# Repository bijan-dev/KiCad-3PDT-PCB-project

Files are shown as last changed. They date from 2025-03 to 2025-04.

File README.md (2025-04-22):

# KiCad-3PDT-PCB-project
A 3PDT PCB for guitar pedals

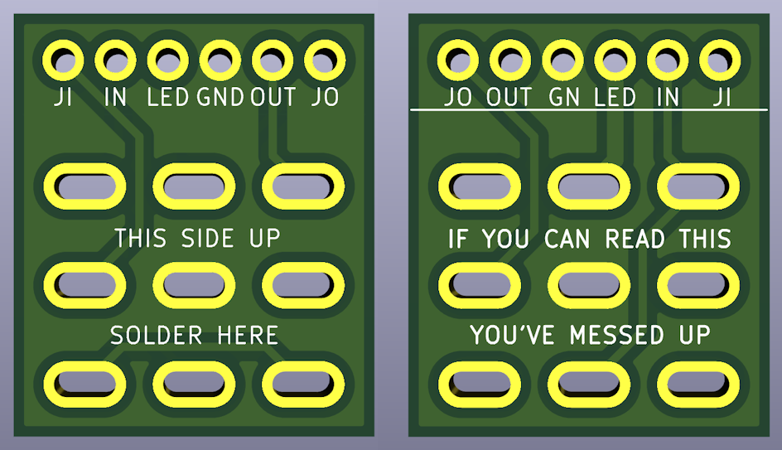
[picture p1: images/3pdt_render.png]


Hello, this is a KiCad project for a 3PDT PCB board.
This will allow a guitar pedal with a 3PDT [like this](https://stompboxparts.com/footswitches/3pdt-footswitch-solder-lug-vimex/) to be wired in true bypass.

* JI = Input Jack
* IN = PCB Input
* LED = LED connection (assumes an offboard current limiting resistor eg. 4.7k Ohm. Please add one if your effect PCB doesn't have one)
* GND = Ground connection
* OUT = PCB Output
* JO = Output Jack

The wire pads have a pitch of 2.54mm (0.1") to match that of common ribbon cables.

Board width is 17.5mm, height is 20.5mm.

Huge thank you to [Mad Bean](https://www.madbeanpedals.com/) for the pad and 3PDT footprints, their footprint library is the GOAT.

---

**This board is now verified!** I ordered some copies from OshPark, and used one in a new build. It works! It's suprisingly tiny!

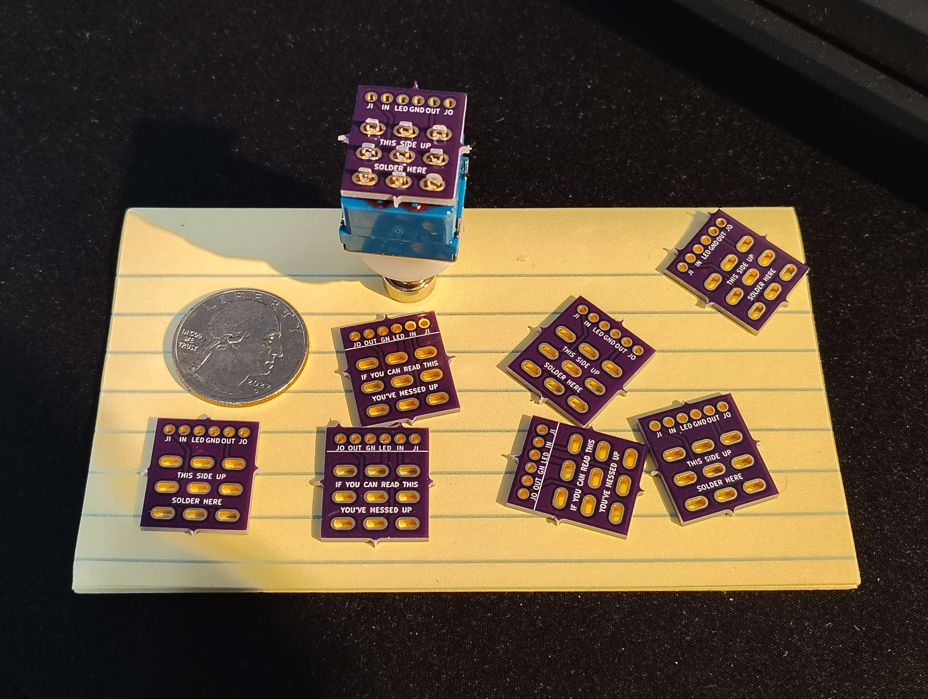
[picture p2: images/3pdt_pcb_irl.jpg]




---

# If you would like to order one

The gerber files are included in the repo.

Click into the `3pdt_pcb_fab_files.zip` file in this repo, then download that zip file.

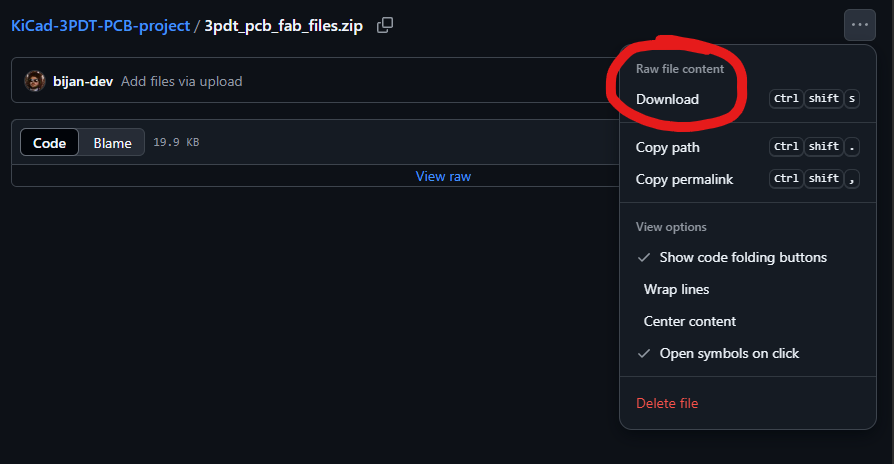
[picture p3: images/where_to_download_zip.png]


Then you can use a board fabricator like JLCPCB and upload that zip onto their site.

If you need the gerber files compressed in a different format than .zip, I've included them in the folder `3pdt_pcb_fab_files`.

Here's where to put the file on JLCPCBs website:

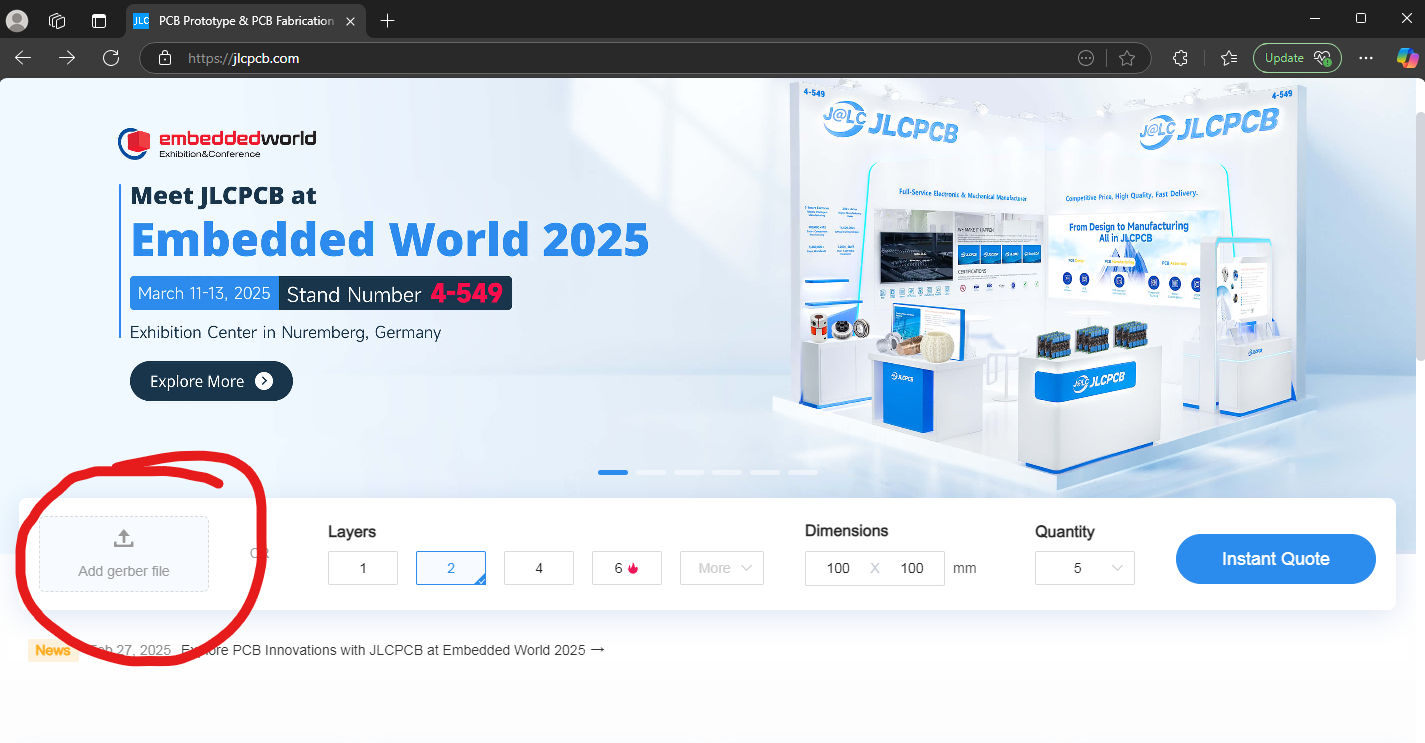
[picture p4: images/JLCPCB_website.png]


Once you drag the .zip onto there, it'll load this page with the PCB, and lots of options for it.
You can click "PCB Qty" to change the number of boards to get. I usually leave everything else default,
except for Surface Finish - LeadFree HASL (personal preference).

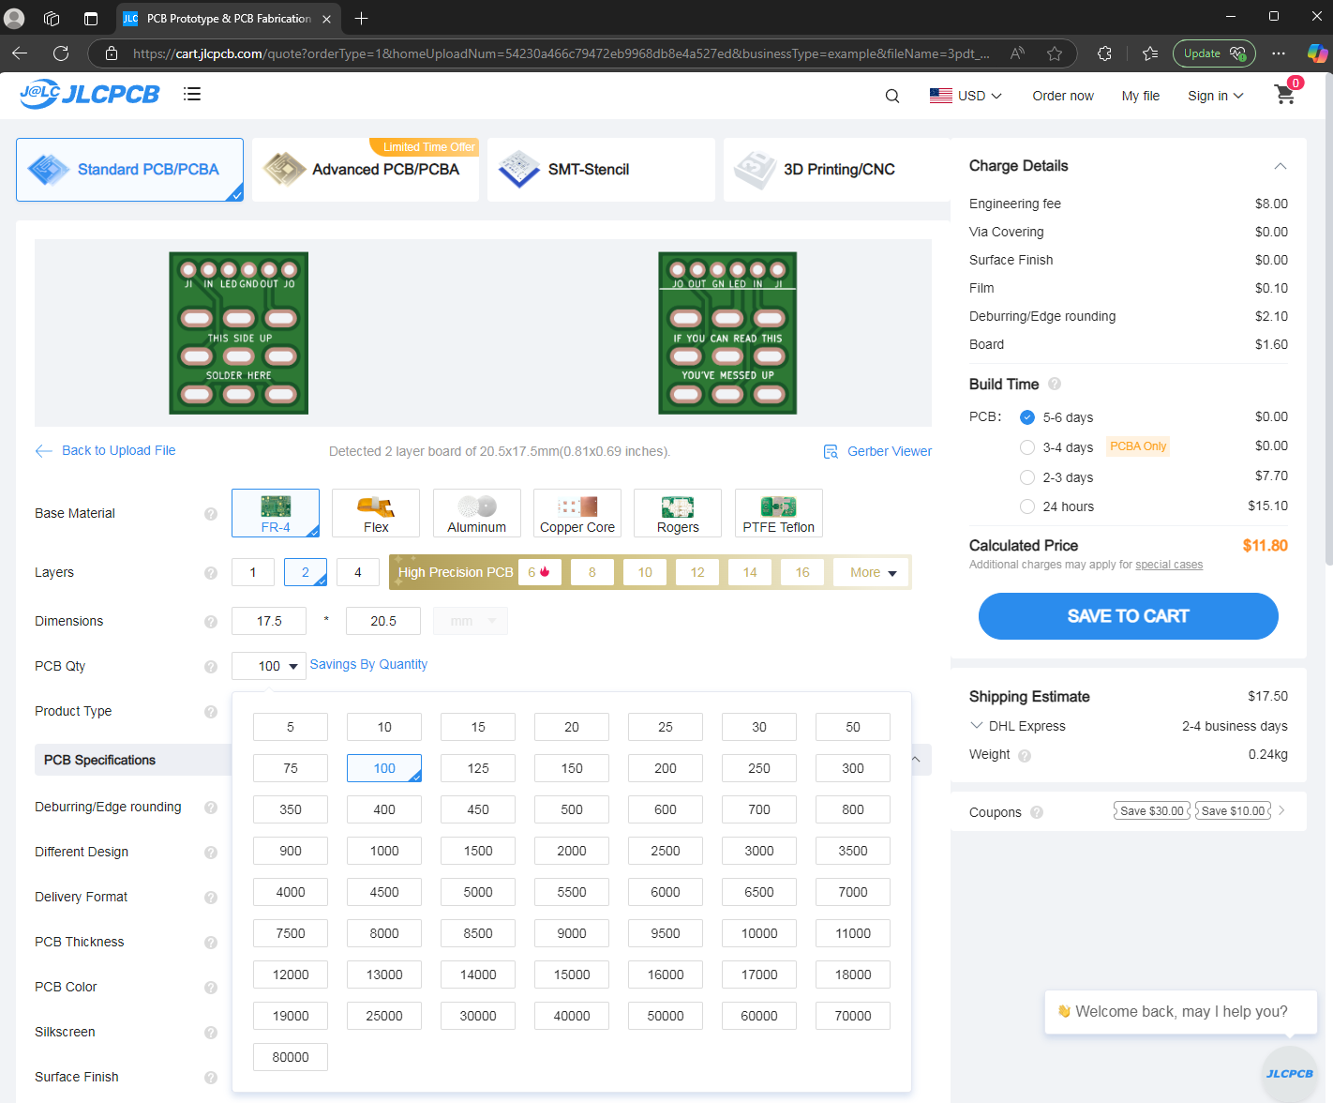
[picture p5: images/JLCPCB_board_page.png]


Other PCB fab sites should work very similarly.

---

# Here's screenshots of the schematic and PCB layout:

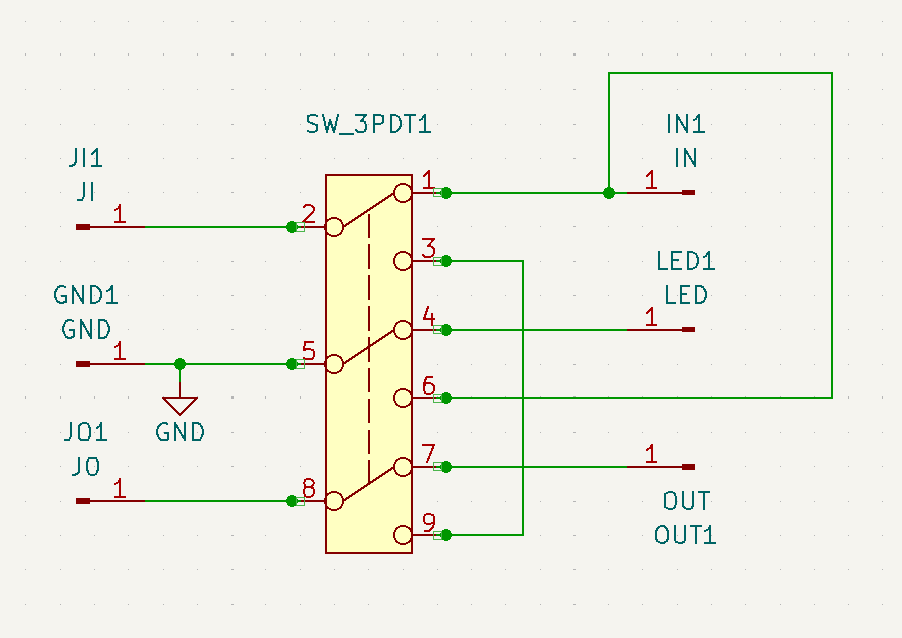
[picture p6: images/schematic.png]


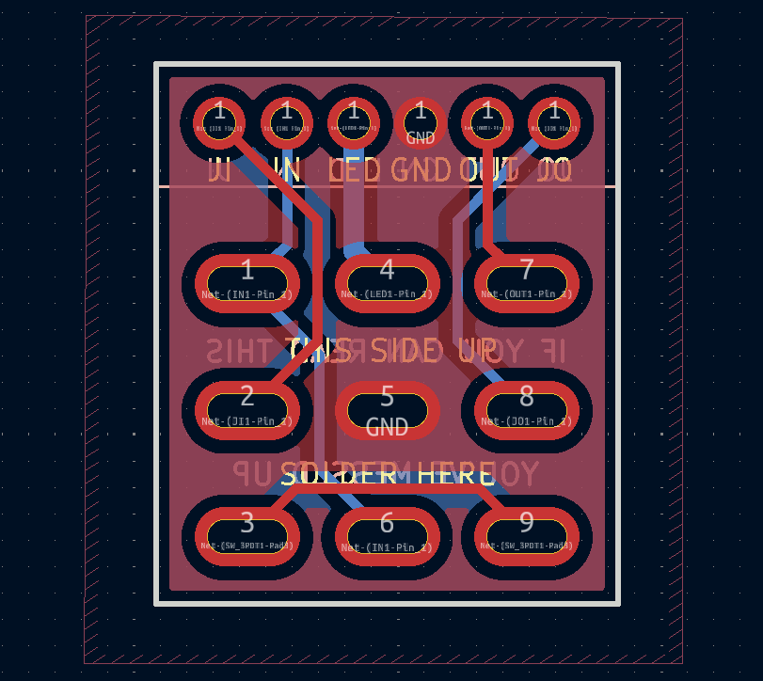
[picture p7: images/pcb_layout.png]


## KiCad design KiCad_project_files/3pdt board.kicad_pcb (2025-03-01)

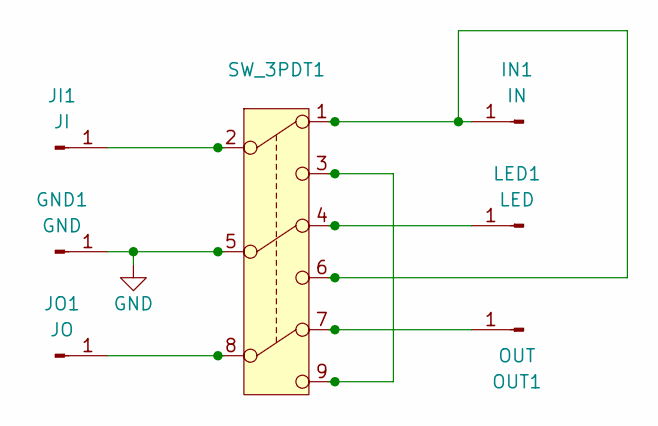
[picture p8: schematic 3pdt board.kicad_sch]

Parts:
GND1: GND; PAD1
IN1: IN; PAD1
JI1: JI; PAD1
JO1: JO; PAD1
LED1: LED; PAD1
OUT1: OUT; PAD1
SW_3PDT1: 3PDT.LUGS.KR.NO_CIRCLE

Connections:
GND: GND1.1, SW_3PDT1.5
unnamed: IN1.1, SW_3PDT1.1, SW_3PDT1.6
unnamed: JI1.1, SW_3PDT1.2
unnamed: JO1.1, SW_3PDT1.8
unnamed: LED1.1, SW_3PDT1.4
unnamed: OUT1.1, SW_3PDT1.7
unnamed: SW_3PDT1.3, SW_3PDT1.9

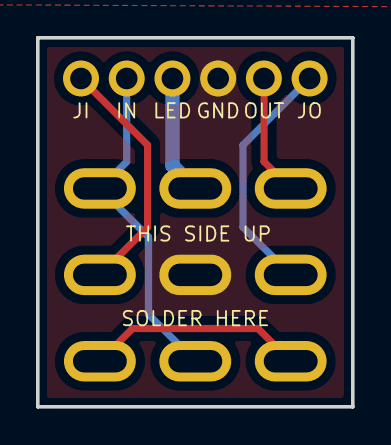
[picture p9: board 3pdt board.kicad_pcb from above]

Board: 2 copper layers, 17.5 x 20.5 mm, 7 parts (0 on the bottom side), 7 nets.

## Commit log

2025-03-01 Rename JLCPCB board page.png to JLCPCB_board_page.png
2025-03-01 update directory name
    [3pdt board-B_Cu.gbr, 3pdt board-B_Mask.gbr, 3pdt board-B_Paste.gbr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]
2025-03-01 rearrange files
    [3pdt board.kicad_pcb, 3pdt board.kicad_sch]
2025-03-01 explain files are gerber
2025-03-01 add schem and pcb layout images
2025-04-22 board is now verified, add images
